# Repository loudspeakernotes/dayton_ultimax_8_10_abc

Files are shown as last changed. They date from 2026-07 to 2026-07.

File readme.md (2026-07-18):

## Dayton Ultimax 8"/10" subwoofer enclosure

Enclosure design for Dayton UMII8-22 Ultimax II 10" or UNII10-22 8" subwoofers.

It's better with the 10" driver but works well for both.

General info for drivers:
[Ultimax 10"](https://www.daytonaudio.com/product/2063/umii10-22-ultimax-ii-10-dvc-subwoofer-2-ohms-per-coil)
[Ultimax 8"](https://www.daytonaudio.com/product/2062/umii8-22-ultimax-ii-8-dvc-subwoofer-2-ohms-per-coil)

Spec sheet for drivers:
[Ultimax 10"](https://www.daytonaudio.com/images/resources/295-710--dayton-audio-UMII10-22-spec-sheet.pdf)
[Ultimax 8"](https://www.daytonaudio.com/images/resources/295-708--dayton-audio-UMII8-22-spec-sheet.pdf)

Enclosure design is based on modelling in WinISD.

Overall box dimensions using 13mm ply/mdf is:
* 376mm wide
* 476mm deep
* 841mm tall

3D model of the enclosure can be viewed at [ultimax_8_10_abc.stl](ultimax_8_10_abc.stl)

OpenSCAD code for generating the model of the enclosure is in [ultimax_8_10_abc.scad](ultimax_8_10_abc.scad)

This enclosure is designed for the frequency range of 27 Hz to 80 Hz

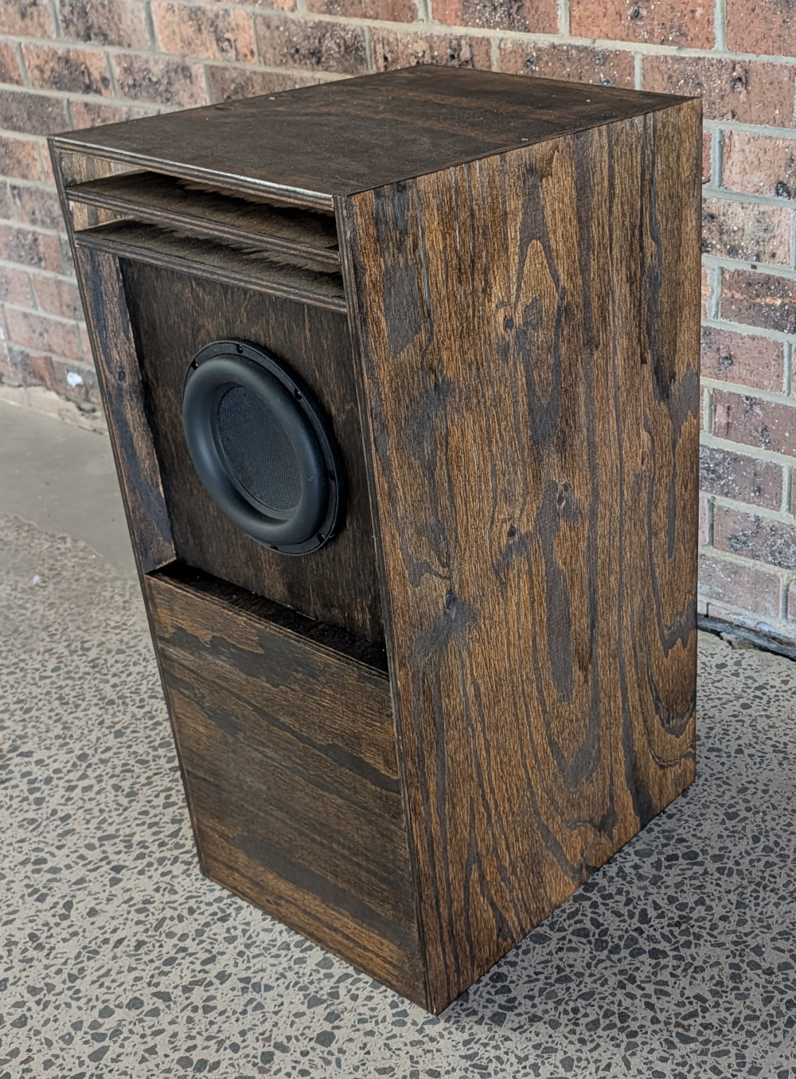
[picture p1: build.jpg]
Build


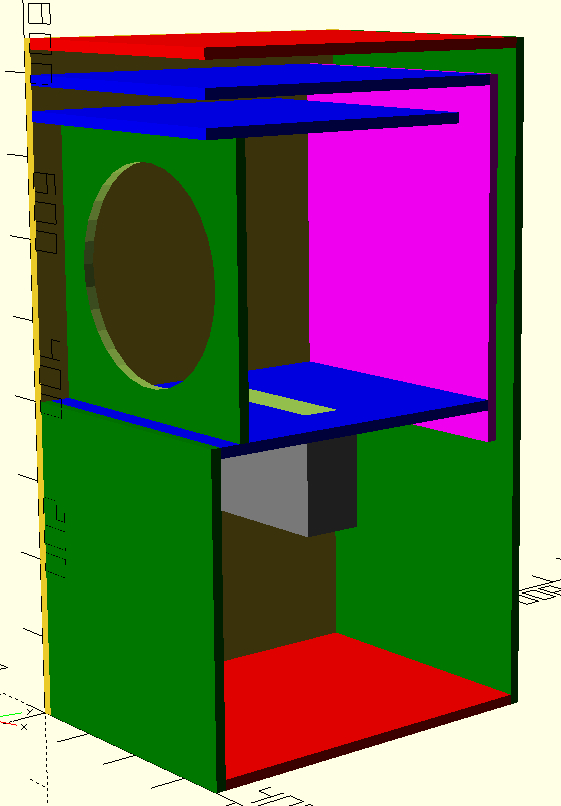
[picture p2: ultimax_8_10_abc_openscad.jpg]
Enclosure overview


## Panel sizes

For 13mm plywood

* Sides: 841 x 476
* Top: 463 x 350
* Bottom: 450 x 350
* Rear: 841 x 350
* Front Bottom: 401 x 350
* Speaker Panel: 341 x 350
* Divider: 407 x 350
* Rear Port Horizontal: 420 x 350
* Rear Port Vertical: 450 x 350
* Front Port Horizontal: 370 x 350

Front and rear ports should have bracing, one against the rear panel and one
each on the horizontal parts of the ports, for a total of 3 braces.

Mid-port between front and rear chamber is inner dimensions of 200mm x 50mm
and is 130mm long.

Front panel is set back 40mm from the front to allow for a grill.

Approx volumes:
Front chamber: 43L
Rear chamber: 61L

## Modelling

Using [WinISD](https://www.linearteam.org/)

Setup:

* 1 Driver
* ABC

Parameters:

* Rear chamber 61 L tuned to 23 Hz
* Front chamber 43 L tuned to 39 Hz
* Rear chamber port square shape 3cm x 35cm
* Front chamber port square shape 3cm x 35cm
* Intrachamber 5cm x 20cm with 13cm vent length
* 500W input signal

Metrics:

8" driver

* Enclosure gain: 7.0 dB at 30.0 Hz
* -3db from peak of 4.0 dB at 27.5 Hz
* -3db at 24.9 Hz
* Peak SPL at 500W: 115 dB at 30.0 Hz
* Peak port air velocity: 28 m/s at 28.9 Hz
* Maximum cone excursion at 500W: 28.5 Hz and 39.1 Hz

10" driver

* Enclosure gain: 4.3 dB at 30.8 Hz
* -3db from peak of 1.3 dB at 27.0 Hz
* -3db at 24.8 Hz
* Peak SPL at 500W: 115 dB at 30.8 Hz
* Peak port air velocity: 29 m/s at 28.7 Hz
* Maximum cone excursion at 500W: 25.6 Hz

The 10" driver can be driven up to 1000W before cone excursion becomes an issue
but for direct comparison the above numbers are all for 500W signal.

Overall the enclosure has a flatter response with a 10" driver, but works well
for both.

## Charts

Results from modelling in WinISD

8" in blue

10" in purple

### Transfer magnitude function

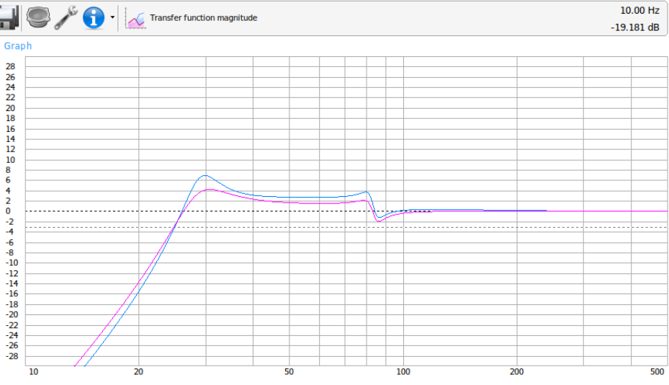
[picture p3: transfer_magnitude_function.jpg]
Transfer magnitude function


### SPL

Using 500W signal for both

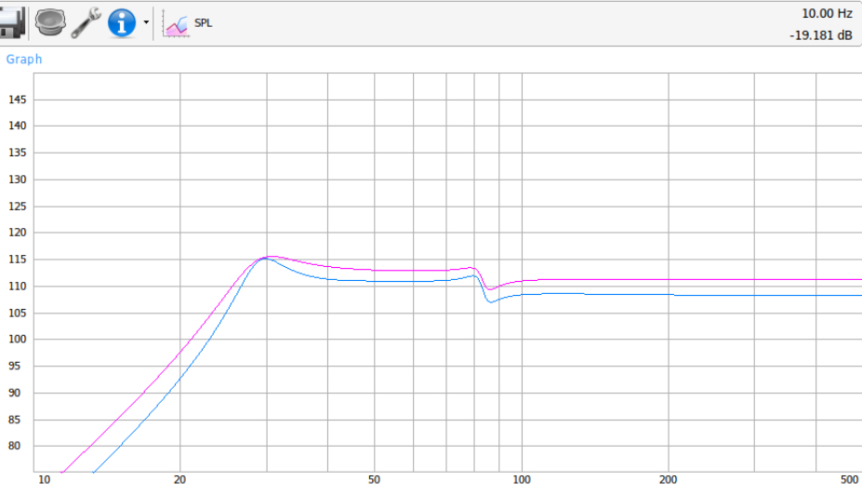
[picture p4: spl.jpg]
Sound pressure level


### Rear port air velocity

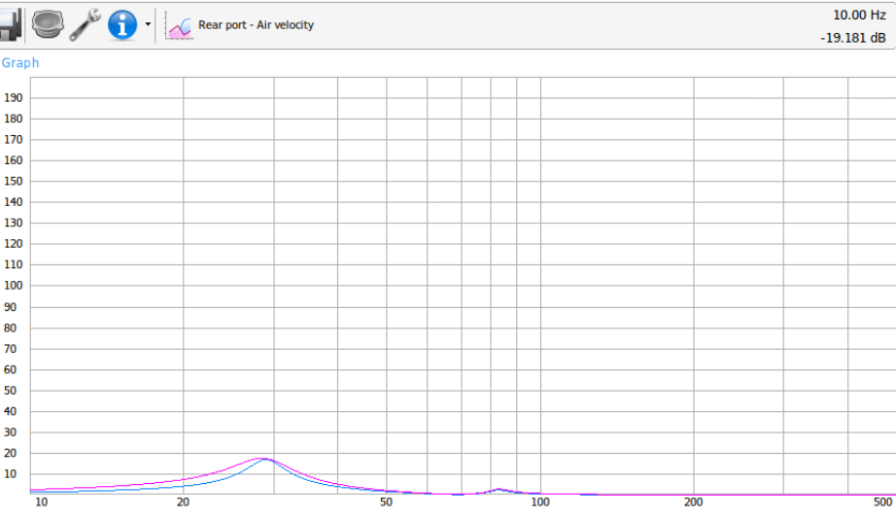
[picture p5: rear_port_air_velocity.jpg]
Rear port air velocity


### Front port air velocity

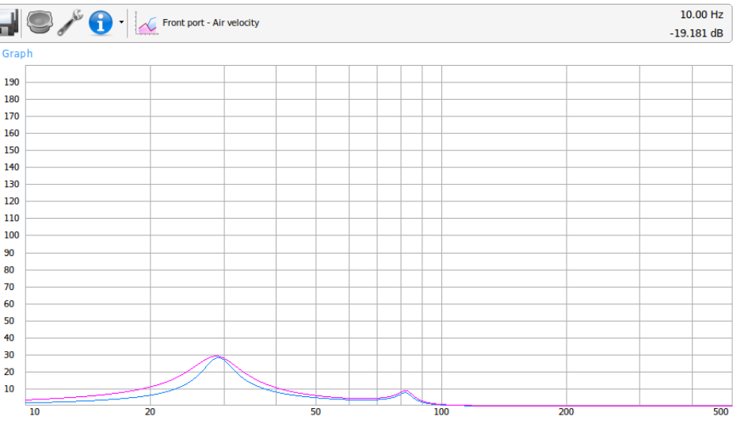
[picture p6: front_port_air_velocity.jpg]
Front port air velocity


### Intrachamber port air velocity

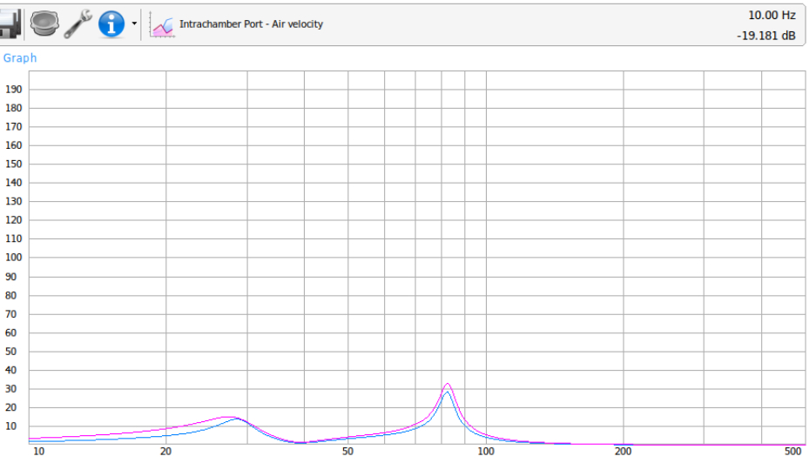
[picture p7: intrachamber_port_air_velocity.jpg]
Intrachamber port air velocity


### Group delay

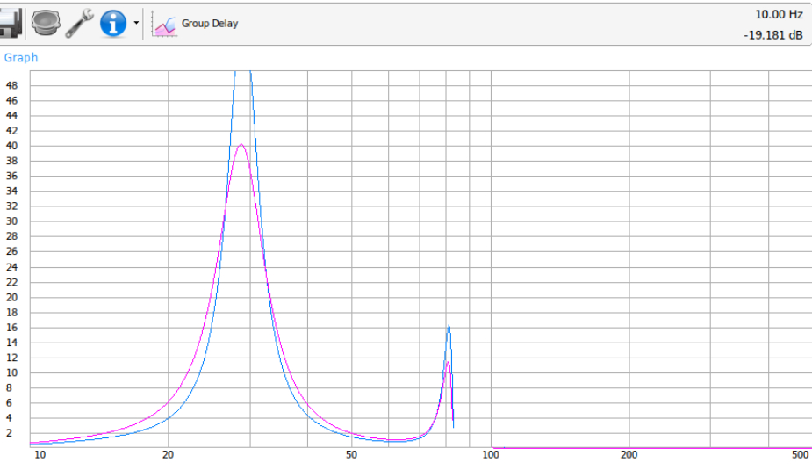
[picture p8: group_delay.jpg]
Group delay


### Cone excursion

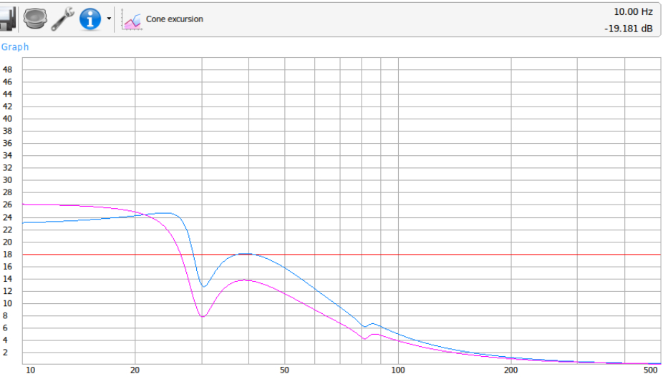
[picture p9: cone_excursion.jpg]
Cone excursion


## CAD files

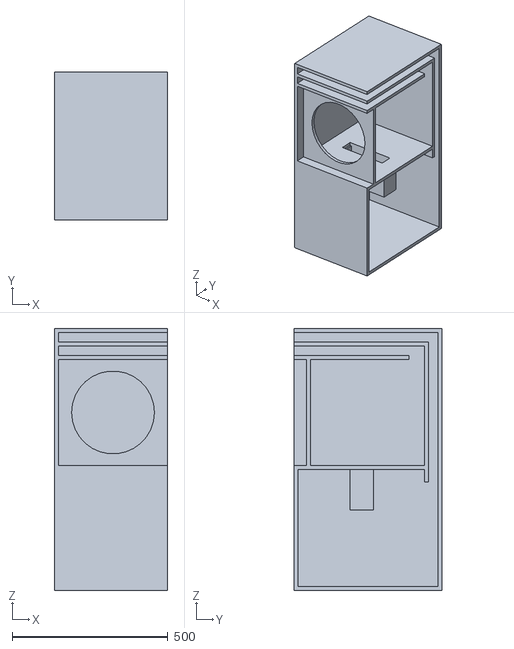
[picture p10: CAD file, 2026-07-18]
ultimax_8_10_abc.stl
363.0 x 476.0 x 841.0

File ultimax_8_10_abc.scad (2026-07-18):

// Aperiodic Bi-Chamber enclosure (ABC)
// for Dayton Ultimax 8" or 10" subwoofer
//
// Ultimax 8
// https://www.daytonaudio.com/product/2062/umii8-22-ultimax-ii-8-dvc-subwoofer-2-ohms-per-coil
// specs
// https://www.daytonaudio.com/images/resources/295-708--dayton-audio-UMII8-22-spec-sheet.pdf
//
// Ultimax 10
// https://www.daytonaudio.com/product/2062/umii8-22-ultimax-ii-8-dvc-subwoofer-2-ohms-per-coil
// specs
// https://www.daytonaudio.com/images/resources/295-708--dayton-audio-UMII8-22-spec-sheet.pdf


// Parameters that can be changed


// sub radius - the largest radius of the basket, ie no bevel
// 107 for 8" sub
// 133 for 10" sub
subr = 133;

ih = 815; // overall inner height

rh = 375; // rear chamber inner height (ie bottom chamber)

t = 13; // plywood timber thickness

mpy = 180; // hardcoded distance of midport from front wall

suby = 40; // how far set back the sub panel is

// Parameters that probably won't change

iw = 350; // inner width
id = 450; // inner depth

ph = 30; // port height

rpl = 900; // rear port length
fpl = 370; // front port length

mpw = 200; // mid port width
mpd = 50; // mid port depth
mpl = 130; // mid port length


// The panels

// left side
translate([0, 0, 0]) {
    d = t+id+t;
    h = t+ih+t;
    cube([t, d, h]);
    echo(str("Left side panel: ", d, " x ", h));
}

// right side
translate([t+iw, 0, 0]) {
    d = t+id+t;
    h = t+ih+t;
    //cube([t, t+id+t, h]);
    echo(str("Right side panel: ", d, " x ", h));
}

// bottom
translate([t, t, 0]) {
    w = iw;
    d = id;
    color("red") cube([iw, d, t]);
    echo(str("Bottom panel: ", w, " x ", d));
}

// top
translate([t, 0, ih+t]) {
    w = iw;
    d = t+id;
    color("red") cube([iw, d, t]);
    echo(str("Top panel: ", w, " x ", d));
}

// rear
translate([t, t+id, 0]) {
    w = iw;
    d = t;
    h = t+ih+t;
    color("green") cube([w, d, h]);
    echo(str("Rear panel: ", h, " x ", w));
}

// front
translate([t, 0, 0]) {
    w = iw;
    d = t;
    h = t + rh + t;
    color("green") cube([w, d, h]);
    echo(str("Front panel: ", h, " x ", w));
}

// sub panel
subph = ih - ph - t - ph - t - rh - t; // sub panel height
translate([t, suby, t+rh+t]) {
    h = subph;
    d = t;
    w = iw;
    difference() {
        color("green") cube([w, d, h]);
        // cutout for sub
        suboffset = (h - subr*2) / 2;
        translate([w/2, -1, h-suboffset-subr]) {
            rotate([-90, 0, 0]) {
                cylinder(r=subr, h=t+2);
            }
        }
    }
    echo(str("Sub panel: ", h, " x ", w));
}

// horizontal divider
translate([t, t, t+rh]) {
    w = iw;
    d = id - ph - t;
    echo(str("Divider: ", d, " x ", w));
    difference() {
        color("blue") cube([w, d, t]);
        // mid port hole
        mpx = (iw - mpw) / 2;
        translate([mpx, mpy, -1]) {
            cube([mpw, mpd, t+2]);
        }
    }
}

// rear port horizontal
rpd = t + id - ph - t; // rear port depth of the ply sheet
translate([t, 0, t+ih-ph-t]) {
    w = iw;
    d = rpd;
    color("blue") cube([w, d, t]);
    echo(str("Rear port horizontal: ", d, " x ", w));
}


// rear port depth path
// ie length of the horizontal part of the rear port
rpdp = rpd + ph/2;
// rear port remaining length after accounting for horizontal part of the part
rprl = rpl - rpdp - ph/2;
// the starting z value for the rear port vertical
rpz = t + ih - ph - rprl;
// rear port vertical
translate([t, rpd, rpz]) {
    w = iw;
    h = rprl;
    color("magenta") cube([w, t, h]);
    echo(str("Rear port vertical: ", h, " x ", w));
}

// front port horizontal
translate([t, 0, t+ih-ph-t-ph-t]) {
    w = iw;
    d = fpl;
    color("blue") cube([w, d, t]);
    echo(str("Front port horizontal: ", d, " x ", w));
}

// mid port
ompw = t + mpw + t; // outer mid port width
ompd = t + mpd + t; // outer mid port depth
mpz = t + rh - mpl;
mpv = ompw * ompd * mpl;
mpx = (t + (iw-mpw)) / 2;
translate([mpx, mpy, mpz]) {
    difference() {
        color("grey") cube([ompw, ompd, mpl]);
        translate([t, t, -1]) {
            cube([mpw, mpd, mpl+2]);
        }
    }
}

// calculate and report some volumes
// front chamber volume
fch = subph;
fcd = id - ph-t - suby;
fcw = iw;
fcv = fch*fcd*fch/1000000;
echo(str("Front chamber volume: ", fcv, " L"));
// rear chamber volume
rch = rh;
rcd = id;
rcw = iw;
rcvnmp = rch*rcd*rch; // rear chamber volume with no mid port
rcv = (rcvnmp - mpv)/1000000;
echo(str("Rear chamber volume: ", rcv, " L"));
